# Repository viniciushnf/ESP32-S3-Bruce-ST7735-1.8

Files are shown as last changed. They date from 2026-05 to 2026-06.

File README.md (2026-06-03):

<p align="center">
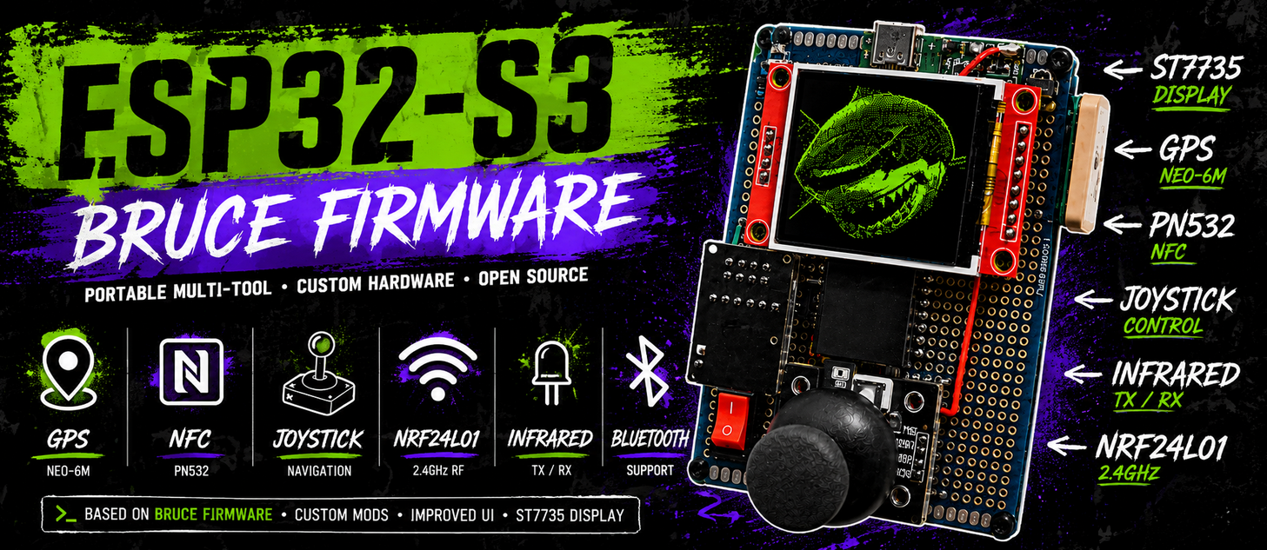
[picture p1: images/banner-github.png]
ESP32-S3 Banner
  
</p>

# ESP32-S3 + Bruce Firmware | 1.8" ST7735 Display, GPS, NFC, NRF24L01, IR & Joystick

This project combines multiple modules into a single portable Bruce Firmware device, including a TFT display, GPS navigation, NFC communication, NRF24L01 RF communication, infrared functionality, joystick control, SD card storage, and battery monitoring.

<p align="center">
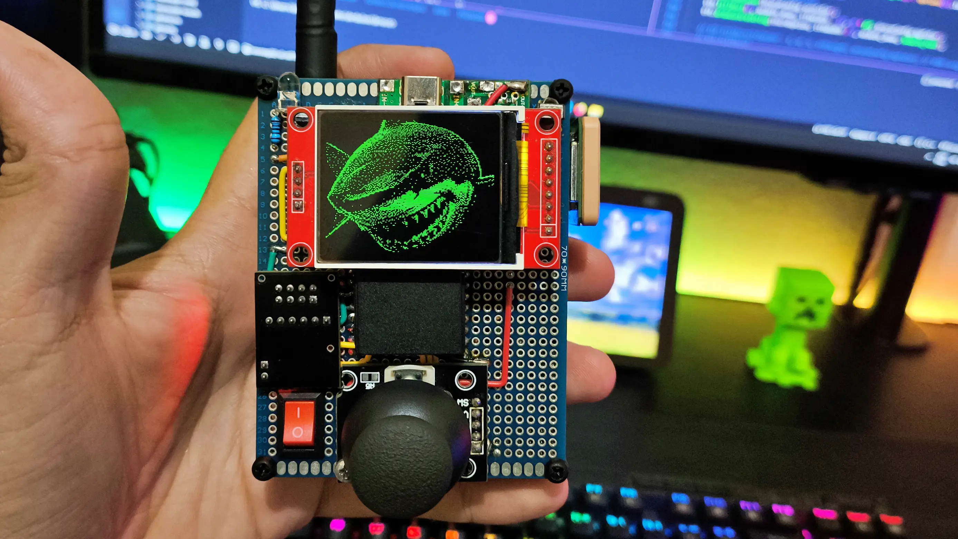
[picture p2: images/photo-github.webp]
ESP32-S3 photo
  
</p>

---

## YouTube Video

<p align="center">
  <a href="https://www.youtube.com/watch?v=Ke6ndQEae68" align="center">
    YouTube Video
  </a>
</p>

**Video:**
https://www.youtube.com/watch?v=Ke6ndQEae68

---

## :zap: Features

### Wi-Fi
- Wi-Fi scanning and network analysis
- Wi-Fi penetration testing tools 
- Packet monitoring and wireless network reconnaissance
- Wi-Fi attacks

### Bluetooth
- Bluetooth device scanning
- Bluetooth Low Energy (BLE) tools
- Bluetooth testing and analysis features

### RF (NRF24L01)
- RF Jammer
- RF Spectrum
- MouseJack

### GPS
- Real-time GPS positioning
- Display latitude, longitude, altitude, speed, and satellite information
- Save GPS data to the SD card

### NFC (PN532)
- Read NFC tags
- Write data to NFC tags
- NFC tag information analysis

### Infrared (IR)
- Receive infrared signals
- Transmit infrared signals
- Store and replay captured IR codes

### SD Card
- Browse files and folders
- Store captured data and logs
- Load and save configuration files

### Power Management
- Battery voltage monitoring
- Rechargeable 18650 battery support
- Integrated charging and voltage regulation

---

## :rocket: Hardware Used

* ESP32-S3
* 1.8" ST7735 TFT Display with SD Card Reader
* NEO-6M GPS Module
* PN532 NFC Module
* NRF24L01 with Adapter
* Infrared Transmitter and Receiver
* Joystick Module
* 18650 Li-ion Battery
* J5019 (TP4056 + MT3608) Battery Charging and 5V Regulation Module

---

## :toolbox: Other Components Used

* Wires
* 2× Perfboards (26 × 31 holes / 70 × 90 mm)
* Nylon Screws and Spacers
* On/Off Switch
* 18650 Battery Holder
* Male and Female Pin Headers
* 1× 100 Ω Resistor
* 1× 220 Ω Resistor
* 1× 1 kΩ Resistor
* 2× 100 kΩ Resistors
* 2× 100 nF Ceramic Capacitors
* 1× 2N2222 Transistor

---

## :clipboard: Wiring Diagram and Documentation

* The module pinout can be found in: wiring-diagram/pinout.txt
* The wiring diagram can be found in: wiring-diagram/wiring-diagram.png
* Hardware assembly photos can be found in: images/
* The installation guide can be found in: installation-guide.txt

---

## :wrench: Bruce Firmware Modifications

* Several Bruce Firmware files were modified to adapt the interface to the 1.8" ST7735 display.
* Additional features and improvements were added to the firmware.
* The installation guide explaining how to upload the modified firmware can be found in: installation-guide.txt

---

## :battery: Battery Life

* During testing, the device achieved more than **8 hours of continuous operation** using a **3000 mAh 18650 Li-ion battery**.
* Actual battery life may vary depending on several factors, including battery capacity and quality, display brightness, active modules, enabled features, wireless activity, and overall device usage.
* As a result, operating time may be shorter or longer than the value observed during testing.

---

## :information_source: Important Notes

* All features were tested under controlled conditions. Performance may vary depending on hardware variations and configuration.
* I recommend testing all components on a breadboard before assembling the final device. Be sure to verify the pinout, operating voltage, and specifications of each module, as different versions may have different requirements.
* Carefully check all power connections and ensure that every module is compatible with your chosen power supply. Testing everything beforehand can help identify wiring issues, compatibility problems, and configuration mistakes before final assembly.

---

## :shark: Bruce Firmware

Official Bruce Firmware project:

* https://bruce.computer/
* https://github.com/BruceDevices/firmware

---

## :warning: Disclaimer

* This project is intended for educational, research, and development purposes only.
* The author assumes no responsibility for any damage to hardware, software, property, legal issues, or data resulting from the use or misuse of the information, files, or materials provided in this repository.
* Users are responsible for ensuring compliance with all applicable laws, regulations, and policies in their jurisdiction. This project should only be used in authorized environments and in a responsible and ethical manner.
* No warranty is provided regarding the accuracy, completeness, reliability, or suitability of the hardware designs, firmware modifications, wiring diagrams, or documentation contained in this repository.
* By using this project, you acknowledge that you do so at your own risk.

---

## :wave: Get in touch

If you build this project, I'd love to see the result! 

If you have any questions, suggestions, or run into any issues, feel free to contact me on Instagram. 

I'm always happy to help, receive feedback, and see what the community creates. 

I'm also open to collaborations and partnership opportunities related to electronics, embedded systems, and open-source projects.

* Instagram: **@viniciushnf**
* https://www.instagram.com/viniciushnf/

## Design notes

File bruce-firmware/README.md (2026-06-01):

Bruce Main Menu

# :shark: Bruce

Bruce is a versatile ESP32 firmware that supports a ton of offensive features focusing on facilitating Red Team operations.
It also supports M5stack and Lilygo products and works great with Cardputer, Sticks, M5Cores, T-Decks and T-Embeds.

**Check our fully open-source hardware too:** https://bruce.computer/boards

## :building_construction: How to install

### The easiest way to install Bruce is using our official Web Flasher!
### Check out: https://bruce.computer/flasher

Alternatively, you can download the latest binary from releases or actions and flash locally using esptool.py
```sh
esptool.py --port /dev/ttyACM0 write_flash 0x00000 Bruce-<device>.bin
```

**For m5stack devices**

If you already use M5Launcher to manage your m5stack device, you can install it with OTA

Or you can burn it directly from the [m5burner tool](https://docs.m5stack.com/en/download), just search for 'Bruce' (My official builds will be uploaded by "owner" and have photos.) on the device category you want to and click on burn

## :keyboard: Discord Server

Contact us in our [Discord Server](https://discord.gg/WJ9XF9czVT)!

## :bookmark_tabs: Wiki

For more information on each function supported by Bruce, [read our wiki here](https://github.com/pr3y/Bruce/wiki).
Also, [read our FAQ](https://github.com/pr3y/Bruce/wiki/FAQ)

## :computer: List of Features

<details>
  <summary><h2>WiFi</h2></summary>

- [x] Connect to WiFi
- [x] WiFi AP
- [x] Disconnect WiFi
- [x] [WiFi Atks](https://github.com/pr3y/Bruce/wiki/WiFi#wifi-atks)
  - [x] [Beacon Spam](https://github.com/pr3y/Bruce/wiki/WiFi#beacon-spam)
  - [x] [Target Atk](https://github.com/pr3y/Bruce/wiki/WiFi#target-atk)
    - [x] Information
    - [x] Target Deauth
    - [x] EvilPortal + Deauth
  - [x] Deauth Flood (More than one target)
- [x] [Wardriving](https://github.com/pr3y/Bruce/wiki/Wardriving)
- [x] [TelNet](https://github.com/pr3y/Bruce/wiki/WiFi#telnet)
- [x] [SSH](https://github.com/pr3y/Bruce/wiki/WiFi#ssh)
- [x] [RAW Sniffer](https://github.com/pr3y/Bruce/wiki/WiFi#raw-sniffer)
- [x] [TCP Client](https://github.com/pr3y/Bruce/wiki/WiFi#tcp-client)
- [x] [TCP Listener](https://github.com/pr3y/Bruce/wiki/WiFi#tcp-listener)
- [x] [Evil Portal](https://github.com/pr3y/Bruce/wiki/WiFi#evil-portal)
- [x] [Scan Hosts](https://github.com/pr3y/Bruce/wiki/WiFi#evil-portal) (with TCP Port scanning)
- [x] [Responder](https://github.com/BruceDevices/firmware/wiki/WiFi#responder)
- [x] [Arp Spoofing](https://github.com/BruceDevices/firmware/wiki/WiFi#arp-spoofing)
- [x] [Arp Poisoning](https://github.com/BruceDevices/firmware/wiki/WiFi#arp-poisoning)
- [x] [Wireguard Tunneling](https://github.com/pr3y/Bruce/wiki/WiFi#wireguard-tunneling)
- [x] Brucegotchi
  - [x] Pwnagotchi friend
  - [x] Pwngrid spam faces & names
    - [x] [Optional] DoScreen a very long name and face
    - [x] [Optional] Flood uniq peer identifiers

</details>

<details>
  <summary><h2>BLE</h2></summary>

- [X] [BLE Scan](https://github.com/pr3y/Bruce/wiki/BLE#ble-scan)
- [X] Bad BLE - Run Ducky scripts, similar to [BadUsb](https://github.com/pr3y/Bruce/wiki/Others#badusb)
- [X] BLE Keyboard - Cardputer and T-Deck Only
- [X] iOS Spam
- [X] Windows Spam
- [X] Samsung Spam
- [X] Android Spam
- [X] Spam All
</details>

<details>
  <summary><h2>RF</h2></summary>

- [x] Scan/Copy
- [x] [Custom SubGhz](https://github.com/pr3y/Bruce/wiki/RF#replay-payloads-like-flipper)
- [x] Spectrum
- [x] Jammer Full (sends a full squared wave into output)
- [x] Jammer Intermittent (sends PWM signal into output)
- [x] Config
    - [X] RF TX Pin
    - [X] RF RX Pin
    - [X] RF Module
        - [x] RF433 T/R M5Stack
        - [x] [CC1101 (Sub-Ghz)](https://github.com/pr3y/Bruce/wiki/CC1101)
    - [X] RF Frequency
- [x] Replay
</details>

<details>
  <summary><h2>RFID</h2></summary>

- [x] Read tag
- [x] Read 125kHz
- [x] Clone tag
- [x] Write NDEF records
- [x] Amiibolink
- [x] Chameleon
- [x] Write data
- [x] Erase data
- [x] Save file
- [x] Load file
- [x] Config
    - [X] [RFID Module](https://github.com/pr3y/Bruce/wiki/RFID#supported-modules)
        - [x] PN532
        - [x] PN532Killer
- [ ] Emulate tag
</details>

<details>
  <summary><h2>IR</h2></summary>

- [x] TV-B-Gone
- [x] IR Receiver
- [x] [Custom IR (NEC, NECext, SIRC, SIRC15, SIRC20, Samsung32, RC5, RC5X, RC6)](https://github.com/pr3y/Bruce/wiki/IR#replay-payloads-like-flipper)
- [x] Config
    - [X] Ir TX Pin
    - [X] Ir RX Pin
</details>

<details>
  <summary><h2>FM</h2></summary>

- [x] [Broadcast standard](https://github.com/pr3y/Bruce/wiki/FM#play_or_pause_button-broadcast-standard)
- [x] [Broadcast reserved](https://github.com/pr3y/Bruce/wiki/FM#no_entry_sign-broadcast-rerserved)
- [x] [Broadcast stop](https://github.com/pr3y/Bruce/wiki/FM#stop_button-broadcast-stop)
- [ ] [FM Spectrum](https://github.com/pr3y/Bruce/wiki/FM#ocean-fm-spectrum)
- [ ] [Hijack Traffic Announcements](https://github.com/pr3y/Bruce/wiki/FM#car-hijack-ta)
- [ ] [Config](https://github.com/pr3y/Bruce/wiki/FM#bookmark_tabs-config)
</details>

<details>
  <summary><h2>NRF24</h2></summary>

- [X] [NRF24 Jammer](https://github.com/pr3y/Bruce/wiki/BLE#nrf24-jammer)
- [X] 2.4G Spectrum
- [ ] Mousejack
</details>

<details>
  <summary><h2>Scripts</h2></summary>

- [X] [JavaScript Interpreter](https://github.com/pr3y/Bruce/wiki/Interpreter) [Credits to justinknight93](https://github.com/justinknight93/Doolittle)
</details>

<details>
  <summary><h2>Others</h2></summary>

- [X] Mic Spectrum
- [X] QRCodes
    - [x] Custom
    - [x] PIX (Brazil bank transfer system)
- [x] [SD Card Mngr](https://github.com/pr3y/Bruce/wiki/Others#sd-card-mngr)
    - [x] View image (jpg)
    - [x] File Info
    - [x] [Wigle Upload](https://github.com/pr3y/Bruce/wiki/Wardriving#how-to-upload)
    - [x] Play Audio
    - [x] View File
- [x] [LittleFS Mngr](https://github.com/pr3y/Bruce/wiki/Others#littlefs-mngr)
- [x] [WebUI](https://github.com/pr3y/Bruce/wiki/Others#webui)
    - [x] Server Structure
    - [x] Html
    - [x] SDCard Mngr
    - [x] Spiffs Mngr
- [x] Megalodon
- [x] [BADUsb (New features, LittleFS and SDCard)](https://github.com/pr3y/Bruce/wiki/Others#badusb)
- [x] USB Keyboard - Cardputer and T-Deck Only
- [x] [iButton](https://github.com/pr3y/Bruce/wiki/Others#ibutton)
- [x] [LED Control](https://github.com/pr3y/Bruce/wiki/Others#led-control)
</details>

<details>
  <summary><h2>Clock</h2></summary>

- [X] RTC Support
- [X] NTP time adjust
- [X] Manual adjust
</details>

<details>
  <summary><h2>Connect (ESPNOW)</h2></summary>

- [X] Send File
- [X] Receive File
- [X] Send Commands
- [X] Receive Commands
</details>

<details>
  <summary><h2>Config</h2></summary>

- [x] Brightness
- [x] Dim Time
- [x] Orientation
- [X] UI Color
- [x] Boot Sound on/off
- [x] Clock
- [x] Sleep
- [x] Restart
</details>

## Specific functions per Device, the ones not mentioned here are available to all.
| Device | CC1101 | NRF24 | FM Radio  | PN532 | Mic | BadUSB | RGB Led | Speaker | Fuel Guage | LITE_VERSION |
| --- | :---: | :---: | :---: | :---: | :---: | :---: | :---: | :---: | :---: | :---: |
| [M5Stack Cardputer](https://shop.m5stack.com/products/m5stack-cardputer-kit-w-m5stamps) (and ADV) | :ok: | :ok: | :ok: | :ok: | :ok:  | :ok: | :ok: | NS4168 | :x: | :x: |
| [M5Stack M5StickC PLUS2](https://shop.m5stack.com/products/m5stickc-plus2-esp32-mini-iot-development-kit)  | :ok: | :ok: | :ok: | :ok: | :ok:  | :ok:¹ | :x: | Tone | :x: | :x: |
| [M5Stack M5StickC PLUS](https://shop.m5stack.com/products/m5stickc-plus-esp32-pico-mini-iot-development-kit) | :ok: | :ok: | :ok: | :ok: | :ok:  | :ok:¹ | :x: | Tone | :x: | :x:² |
| [M5Stack M5Core BASIC](https://shop.m5stack.com/products/basic-core-iot-development-kit) | :ok: | :ok: | :ok: | :ok: | :ok:  | :ok:¹ | :x: | Tone | :x: | :x: |
| [M5Stack M5Core2](https://shop.m5stack.com/products/m5stack-core2-esp32-iot-development-kit-v1-1) | :ok: | :ok: | :ok: | :ok: | :ok:  | :ok:¹ | :x: | :x: | :x: | :x: |
| [M5Stack M5CoreS3](https://shop.m5stack.com/products/m5stack-cores3-esp32s3-lotdevelopment-kit)/[SE](https://shop.m5stack.com/products/m5stack-cores3-se-iot-controller-w-o-battery-bottom) | :ok: | :ok: | :ok: | :ok: | :x: | :ok: | :x: | :x: | :x: | :x: |
| [JCZN CYD&#x2011;2432S028](https://www.aliexpress.us/item/3256804774970998.html) | :ok: | :ok: | :ok: | :ok: | :x: | :ok:¹ | :x: | :x: | :x: | :x:² |
| [Lilygo T&#x2011;Embed CC1101](https://lilygo.cc/products/t-embed-cc1101) | :ok: | :ok: | :ok: | :ok: | :ok:  | :ok: | :ok: | :ok: | :ok: | :x: |
| [Lilygo T&#x2011;Embed](https://lilygo.cc/products/t-embed) | :ok: | :ok: | :ok: | :ok: | :ok:  | :ok: | :ok: | :ok: | :x: | :x: |
| [Lilygo T-Display-S3](https://lilygo.cc/products/t-display-s3) | :ok: | :ok: | :x: | :x: | :x: | :ok: | :x: | :x: | :x: | :x: |
| [Lilygo T&#x2011;Deck](https://lilygo.cc/products/t-deck) ([and pro](https://lilygo.cc/products/t-deck-plus-1)) | :ok: | :x: | :x: | :x: | :x: | :ok: | :x: | :x: | :x: | :x: |
| [Lilygo T-Watch-S3](https://lilygo.cc/products/t-watch-s3) | :x: | :x: | :x: | :x: | :x: | :ok: | :x: | :x: | :x: | :x: |
| [Lilygo T-LoRa Pager](https://lilygo.cc/products/t-lora-pager) | :x: | :x: | :x: | :x: | :x: | :ok: | :x: | :x: | :x: | :x: |
| [Smoochiee V2](https://www.pcbway.com/project/shareproject/Bruce_PCB_Smoochiee_d6a0284b.html) | :ok: | :ok: | :x: | :ok: | :x: | :ok: | :x: | :x: | :x: | :x: |
| [ESP32-C5](https://docs.espressif.com/projects/esp-dev-kits/en/latest/esp32c5/esp32-c5-devkitc-1/user_guide.html) | :ok: | :ok: | :x: | :ok: | :x: | :x: | :x: | :x: | :x: | :x: |
| [Bruce RF Reaper](https://www.elecrow.com/bruce-pcb-rf-reaper.html) | :ok: | :ok: | :x: | :x: but w/ ST25R3916 | :x: | :ok: | :ok: | :x: | :ok: | :x: |

² CYD have a LITE_VERSION version for Launcher Compatibility
¹ Core, CYD and StickCs Bad-USB: [here](https://github.com/pr3y/Bruce/wiki/Others#badusb)

*LITE_VERSION*: TelNet, SSH, WireGuard, ScanHosts, RawSniffer, Brucegotchi, BLEBacon, BLEScan and Interpreter are NOT available for M5Launcher Compatibility

## :sparkles: Why and how does it look?

Bruce stems from a keen observation within the community focused on devices like Flipper Zero. While these devices offered a glimpse into the world of offensive security, there was a palpable sense that something more could be achieved without being that overpriced, particularly with the robust and modular hardware ecosystem provided by ESP32 Devices, Lilygo and M5Stack products.

Bruce Main Menu
Bruce on M5Core
Bruce on Stick
Bruce on CYD

Other media can be [found here](./media/).

## :clap: Acknowledgements

+ [@bmorcelli](https://github.com/bmorcelli) for new core and a bunch of new features, also porting to many devices!
+ [@IncursioHack](https://github.com/IncursioHack) for adding RF and RFID modules features.
+ [@Luidiblu](https://github.com/Luidiblu) for logo and UI design assistance.
+ [@eadmaster](https://github.com/eadmaster) for adding a lot of features.
+ [@rennancockles](https://github.com/rennancockles) for a lot of RFID code, refactoring and others features.
+ [@7h30th3r0n3](https://github.com/7h30th3r0n3) refactoring and a lot of help with WiFi attacks.
+ [@Tawank](https://github.com/Tawank) refactoring interpreter among many other things
+ [@pablonymous]() new RF functions to read RAW Data
+ [Smoochiee]() for Bruce PCB design.
+ [TH3_KR4K3N]() for Stick cplus extender PCB design.
+ Everyone who contributed in some way to the project, thanks :heart:

## :construction: Disclaimer

Bruce is a tool for cyber offensive and red team operations, distributed under the terms of the Affero General Public License (AGPL). It is intended for legal and authorized security testing purposes only. Use of this software for any malicious or unauthorized activities is strictly prohibited. By downloading, installing, or using Bruce, you agree to comply with all applicable laws and regulations. This software is provided free of charge, and we do not accept payments for copies or modifications. The developers of Bruce assume no liability for any misuse of the software. Use at your own risk.

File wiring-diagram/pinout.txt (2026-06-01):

Module pin ---> ESP32-S3 GPIO

---- DISPLAY ----
LED BL -----> 4
SCK (SCLK) -> 5
SDA (MOSI) -> 6
AO (DC) ----> 7
RESET ------> 15
CS ---------> 16

---- SD CARD ----
CS ---> 40
MOSI -> 6
MISO -> 41
SCK --> 5

--- NRF24L01 -----
CE -----> 21
CSN/SS -> 47
SCK ----> 5
MOSI ---> 6
MISO ---> 41
IRQ ----> 35

---- JOYSTICK ----
VR-X -> 12
VR-Y -> 13
SW ---> 14

------ I2C ------
SDA -> 18
SCL -> 8

------- IR -------
TX -> 1
RX -> 2

------ GPS ------
GPS TX -> 38 (RX)
GPS RX -> 17 (TX)

---- BATTERY ----
BAT -> 10

- - - - - - - - -

Attention:

I recommend testing all components on a breadboard before assembling the final device. Be sure to verify the pinout,
operating voltage, and specifications of each module, as different versions may have different requirements.

Carefully check the power connections and ensure that all modules are compatible with your chosen power supply.
Testing everything beforehand can help identify wiring issues, compatibility problems, and configuration mistakes before the final assembly.

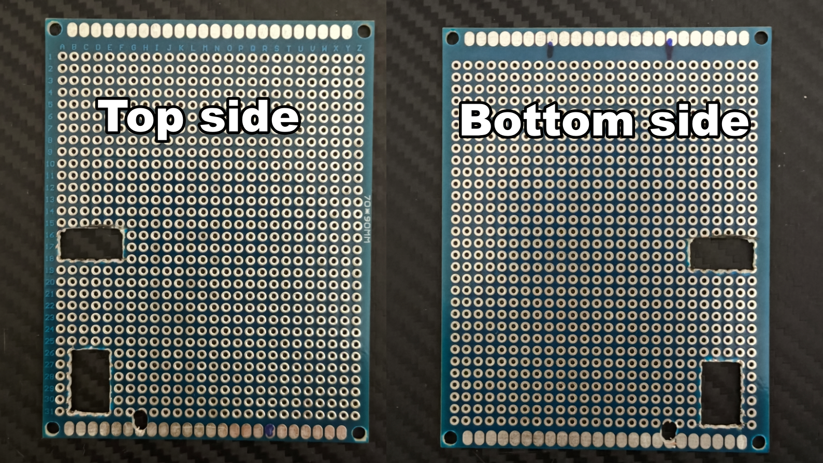
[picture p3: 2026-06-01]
images/holes-in-the-PCB-1.png

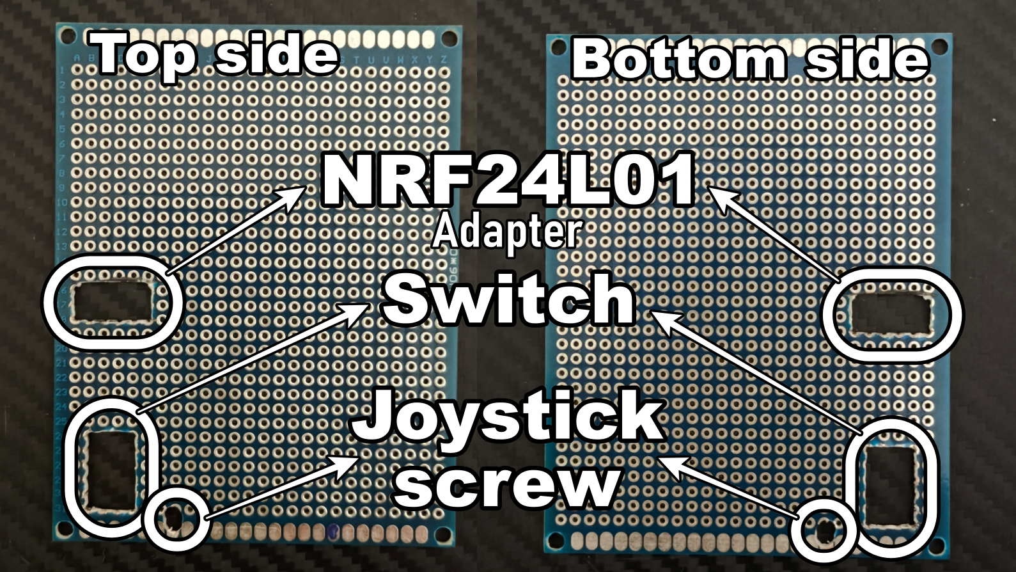
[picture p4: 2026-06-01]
images/holes-in-the-PCB-2.png

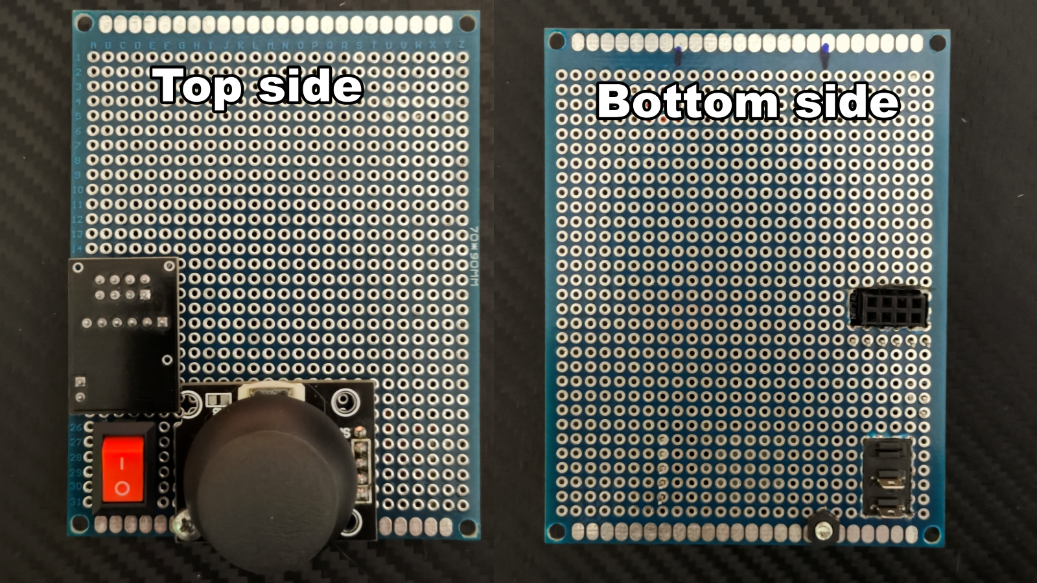
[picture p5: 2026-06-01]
images/holes-in-the-PCB-3.png

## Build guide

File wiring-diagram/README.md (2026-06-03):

# PINOUT

## :electric_plug: Module pin ---> ESP32-S3 GPIO

### Display

| Display Pin | ESP32-S3 |
|---|---|
| LED BL | GPIO 4 |
| SCK (SCLK) | GPIO 5 |
| SDA (MOSI) | GPIO 6 |
| A0 (DC) | GPIO 7 |
| RESET | GPIO 15 |
| CS | GPIO 16 |

### SD Card

| SD Card Pin | ESP32-S3 |
|---|---|
| CS | GPIO 40 |
| MOSI | GPIO 6 |
| MISO | GPIO 41 |
| SCK | GPIO 5 |

### NRF24L01

| NRF24L01 Pin | ESP32-S3 |
|---|---|
| CE | GPIO 21 |
| CSN / SS | GPIO 47 |
| SCK | GPIO 5 |
| MOSI | GPIO 6 |
| MISO | GPIO 41 |
| IRQ | GPIO 35 |

### Joystick

| Joystick Pin | ESP32-S3 |
|---|---|
| VR-X | GPIO 12 |
| VR-Y | GPIO 13 |
| SW | GPIO 14 |

### I2C

| I2C Pin | ESP32-S3 |
|---|---|
| SDA | GPIO 18 |
| SCL | GPIO 8 |

### Infrared

| IR Pin | ESP32-S3 |
|---|---|
| TX | GPIO 1 |
| RX | GPIO 2 |

### GPS

| GPS Pin | ESP32-S3 |
|---|---|
| GPS TX → ESP32 RX | GPIO 38 |
| GPS RX → ESP32 TX | GPIO 17 |

### Battery Monitoring

| Signal | ESP32-S3 |
|---|---|
| BAT | GPIO 10 |

---

<p align="center">
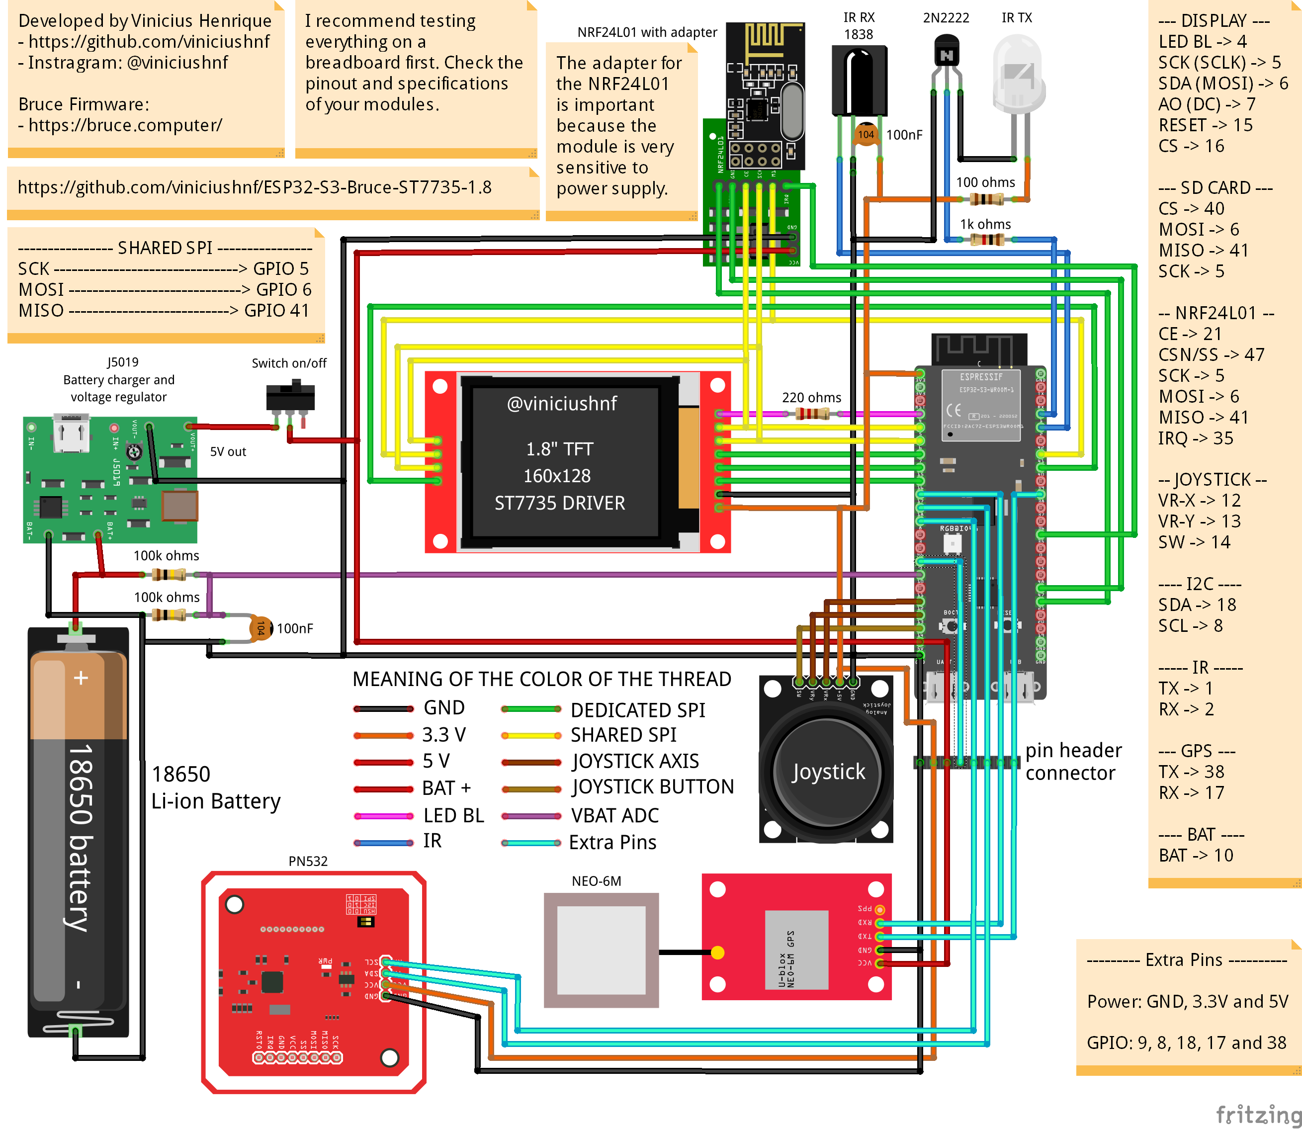
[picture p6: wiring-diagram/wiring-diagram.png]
ESP32-S3 pinout
  
</p>

---

## :warning: Attention:

* I recommend testing all components on a breadboard before assembling the final device. Be sure to verify the pinout,
operating voltage, and specifications of each module, as different versions may have different requirements.

* Carefully check the power connections and ensure that all modules are compatible with your chosen power supply.

* Testing everything beforehand can help identify wiring issues, compatibility problems, and configuration mistakes before the final assembly.

---

## :battery: Battery Charger and Monitoring Circuit

* This project uses a J5019 module, which combines a TP4056 Li-ion battery charger and an MT3608 boost converter. The TP4056 safely charges the 18650 battery, while the MT3608 boosts the battery voltage to a stable 5V output for the ESP32-S3.

* Battery voltage is monitored using a voltage divider made of two 100 kΩ resistors, reducing the battery voltage by half before it reaches the ESP32-S3 ADC pin. This is necessary because a Li-ion battery can reach 4.2V, which is too high for direct ADC measurement.

* A 100 nF capacitor helps filter noise and improves battery voltage readings. Always verify your module specifications and test the circuit before final assembly.

---

## :information_source: NRF24L01 adapter

* The NRF24L01 is sensitive to power supply fluctuations and can become unstable when powered directly from the ESP32-S3. 

* The NRF24L01 adapter includes a voltage regulator and filtering capacitors that provide a stable 3.3V supply, improving reliability, communication range, and overall performance. 

* Using the adapter is highly recommended to prevent connection issues, random resets, and packet loss.

---

## :bulb: Infrared Transmitter Circuit

* The 2N2222 transistor is used to drive the infrared transmitting LED. 

* An ESP32-S3 GPIO cannot safely provide the current required for a powerful IR transmission, so the transistor acts as a switch that allows the LED to draw more current directly from the power supply. 

* This increases the infrared signal strength, improves transmission range, and helps protect the ESP32-S3 GPIO from excessive current.

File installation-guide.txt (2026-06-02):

ESP32-S3 Bruce Firmware Installation Guide

This guide explains how to install and upload the modified Bruce Firmware included in this repository to an ESP32-S3 board.

Repository:
https://github.com/viniciushnf/ESP32-S3-Bruce-ST7735-1.8

------------------------------------------------

OPTION 1 - BUILD AND UPLOAD THE SOURCE CODE
(RECOMMENDED FOR CUSTOMIZATION AND DEVELOPMENT)

Requirements:

* ESP32-S3 board
* USB data cable
* Visual Studio Code
* PlatformIO extension for VS Code
* Python 3.x

Step 1 - Download the Repository

* Download or clone this repository: https://github.com/viniciushnf/ESP32-S3-Bruce-ST7735-1.8

* The modified Bruce Firmware source code is located in: bruce-firmware/

Step 2 - Install Python

Download and install Python: https://www.python.org/downloads/

Important:

During installation, enable the option: "Add Python to PATH"

Verify the installation:

Open a terminal and run:
python --version
or
python3 --version

Step 3 - Install Visual Studio Code

Download and install Visual Studio Code: https://code.visualstudio.com/

Step 4 - Install PlatformIO

1. Open Visual Studio Code.
2. Open the Extensions tab.
3. Search for:

PlatformIO IDE

4. Install the extension.
5. Restart Visual Studio Code if required.

Step 5 - Open the Firmware Project

1. Open Visual Studio Code.

2. Select: File -> Open Folder

3. Open the folder: bruce-firmware

4. Wait for PlatformIO to initialize the project.

The first initialization may take several minutes because PlatformIO will automatically download the required toolchains and libraries.

Step 6 - Connect the ESP32-S3

Connect the ESP32-S3 board to the computer using a USB data cable.

Wait for the operating system to recognize the device.

Step 7 - Verify the Selected Environment

Open the file: platformio.ini

Verify that the correct ESP32-S3 environment is selected for your hardware.

The repository already contains the configuration used for this project.

Step 8 - Compile the Firmware

Click the Build button in PlatformIO or run: pio run

The compilation process may take several minutes during the first build.

Step 9 - Upload the Firmware

Click the Upload button in PlatformIO or run: pio run --target upload

Wait until the upload process finishes successfully.

Step 10 - Monitor the Serial Port (Optional)

To open the serial monitor:
pio device monitor
or use the PlatformIO Serial Monitor button.

------------------------------------------------

OPTION 2 - FLASH THE PRECOMPILED BIN FILE
(FASTEST METHOD)

This is the easiest way to install Bruce Firmware on the ESP32-S3 without compiling the source code.

The precompiled firmware file is located in: bruce-firmware/Bruce-esp32-s3-st7735.bin

Requirements:
* ESP32-S3 board
* USB cable
* Google Chrome browser (recommended)
* Internet connection

I strongly recommend using Google Chrome to access the ESPTool Web Flasher. Other browsers may also work, but Chrome currently provides the best compatibility and Web Serial support.

ESPTool Web Flasher: https://espressif.github.io/esptool-js/

Tested Hardware:
This procedure was tested on an ESP32-S3-WROOM-1-N16R8 and worked perfectly.

The N16R8 version has:
* 16 MB Flash
* 8 MB PSRAM

Installation Steps:

1. Connect the ESP32-S3 to your computer using a USB cable.

2. Open Google Chrome.

3. Open the ESPTool Web Flasher: https://espressif.github.io/esptool-js/

4. Click "Connect".

5. Select the correct COM port for your ESP32-S3.

6. Click "Erase Flash".
(This step is highly recommended because it removes old firmware, partition tables, and flash configurations that could prevent the firmware from booting correctly.)

7. After the erase process finishes, select the firmware file: Bruce-esp32-s3-st7735.bin
* located in: bruce-firmware/Bruce-esp32-s3-st7735.bin

8. Configure the flashing parameters exactly as follows:
* Address: 0x0
* Flash Mode: DIO
* Flash Frequency: 40M
* Flash Size: 16 MB

9. Click "Program".

10. Wait for the flashing process to complete.

11. After the upload finishes, the ESP32-S3 may not automatically reboot. If that happens, simply disconnect and reconnect power, or press the RESET button.

12. The Bruce Firmware should now start normally.

Notes for ESP32-S3 N16R8 Users

If your board is an ESP32-S3-WROOM-1-N16R8, use:
* Address: 0x0
* Flash Mode: DIO
* Flash Frequency: 40M
* Flash Size: 16 MB

These settings were tested and verified to work correctly.

What If My ESP32-S3 Is Not an N16R8?

The most important parameter is the Flash Size.

Different ESP32-S3 modules may have different flash capacities:

N4  = 4 MB Flash
N8  = 8 MB Flash
N16 = 16 MB Flash
N32 = 32 MB Flash

If your board is not an N16R8, select the Flash Size that matches your hardware.

Examples:

ESP32-S3 N8:
Flash Size = 8 MB

ESP32-S3 N16:
Flash Size = 16 MB

ESP32-S3 N32:
Flash Size = 32 MB

You can usually find the flash size:

* Printed on the module
* In the product specifications
* In the board documentation

If you are unsure about your board specifications, check the manufacturer's documentation before flashing.

Troubleshooting

Firmware uploads successfully but does not boot:
* Perform "Erase Flash" again.
* Reflash the firmware.
* Verify that Flash Size matches your hardware.
* Verify that Address is set to 0x0.
* Verify that Flash Mode is set to DIO.
* Verify that Flash Frequency is set to 40M.

ESP32-S3 does not reboot automatically:
* Press the RESET button.
* Or disconnect and reconnect power.

The firmware was successfully tested using:
* ESP32-S3-WROOM-1-N16R8
* Flash Size: 16 MB
* Flash Mode: DIO
* Flash Frequency: 40M
* Address: 0x0
* ESPTool Web Flasher (Chrome)
------------------------------------------------

### IMPORTANT NOTES ###

* Verify all wiring before powering the device.
* Make sure the display, GPS, NFC, NRF24L01, infrared modules, joystick, and other peripherals are connected according to the wiring diagram provided in this repository.
* Different module versions may use different pinouts or operating voltages.
* Always check the specifications of your hardware before connecting power.
* If the board is not detected, verify the USB cable and install the appropriate USB-to-Serial drivers if required.
* Some ESP32-S3 boards may require entering bootloader mode manually during flashing.

Additional Documentation:

* Wiring diagram: wiring-diagram/
* Pinout information: wiring-diagram/pinout.txt
* Hardware photos: images/

For additional information about Bruce Firmware, visit:

https://bruce.computer/
https://github.com/BruceDevices/firmware

------------------------------------------------

Disclaimer:

* This project is intended for educational, research, and development purposes only.
* The author assumes no responsibility for any damage to hardware, software, property, legal issues, or data resulting from the use or misuse of the information, files, or materials provided in this repository.
* Users are responsible for ensuring compliance with all applicable laws, regulations, and policies in their jurisdiction. This project should only be used in authorized environments and in a responsible and ethical manner.
* No warranty is provided regarding the accuracy, completeness, reliability, or suitability of the hardware designs, firmware modifications, wiring diagrams, or documentation contained in this repository.
* By using this project, you acknowledge that you do so at your own risk.

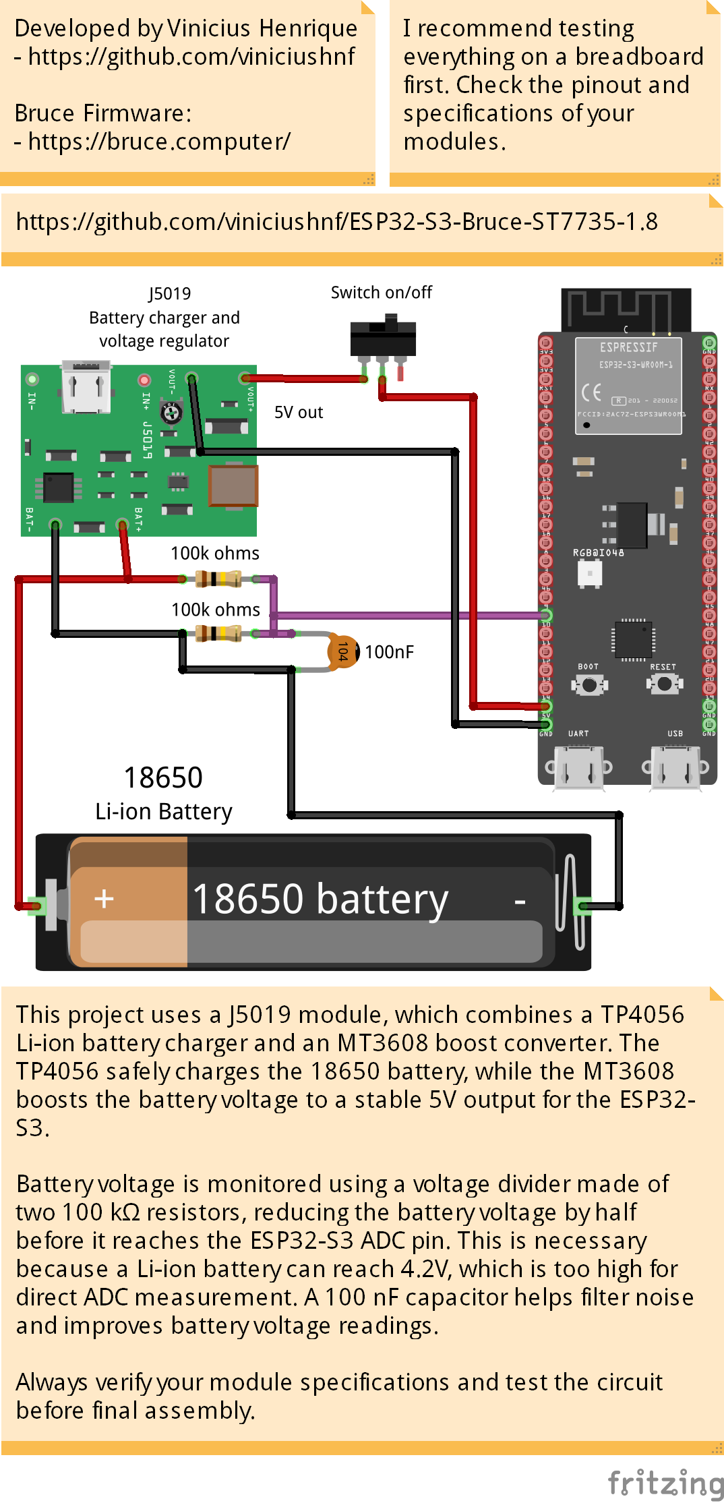
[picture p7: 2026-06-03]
wiring-diagram/power-circuit.png

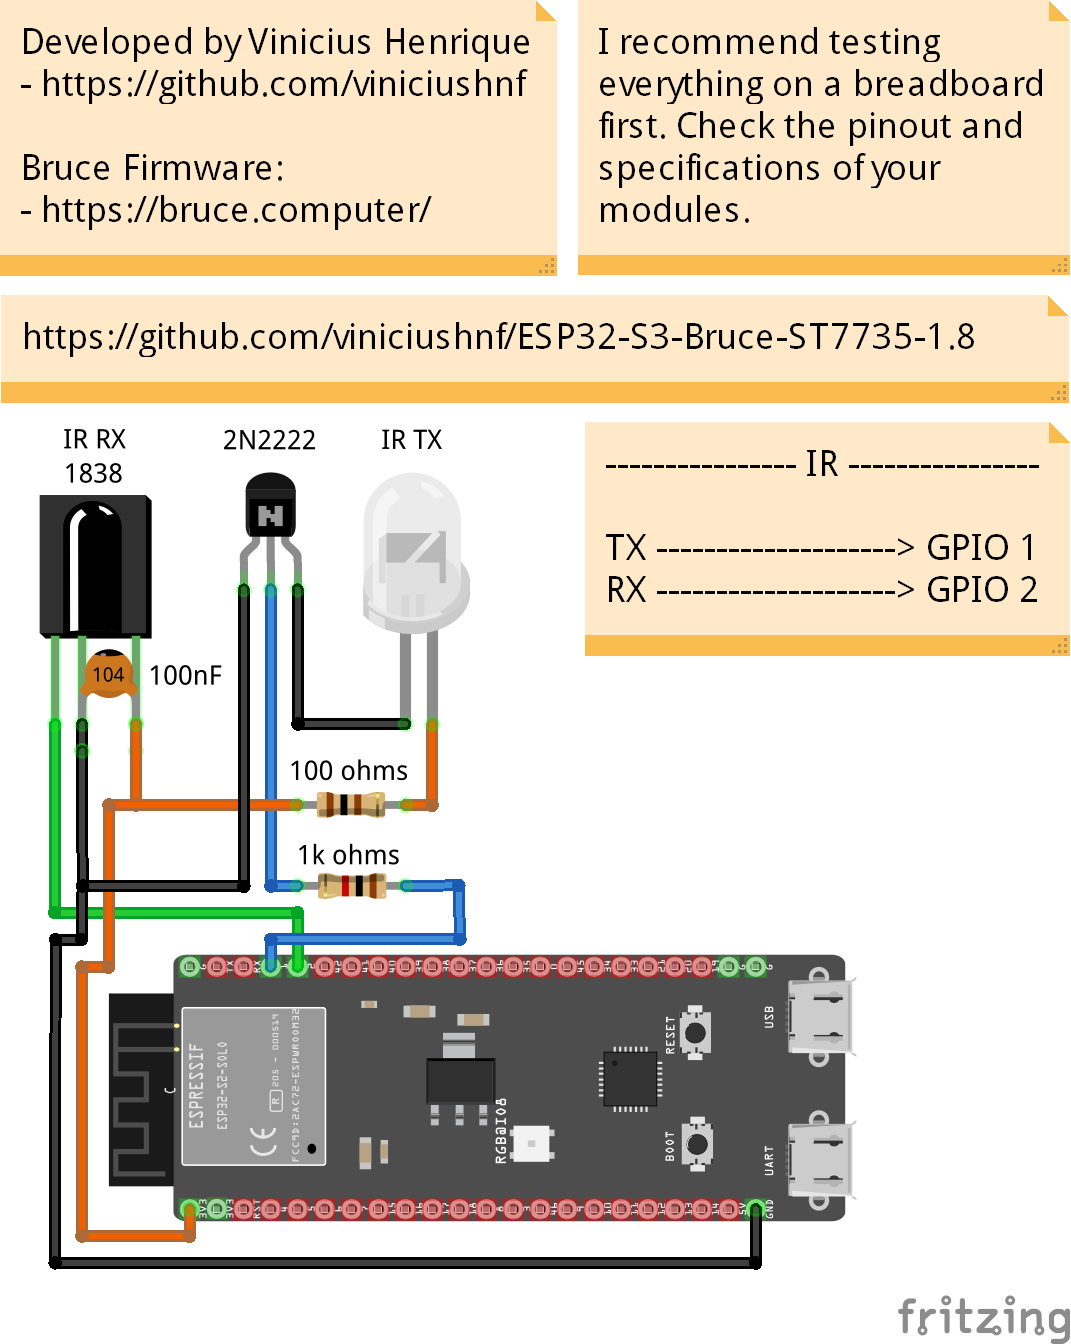
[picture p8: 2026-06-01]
wiring-diagram/ir.png

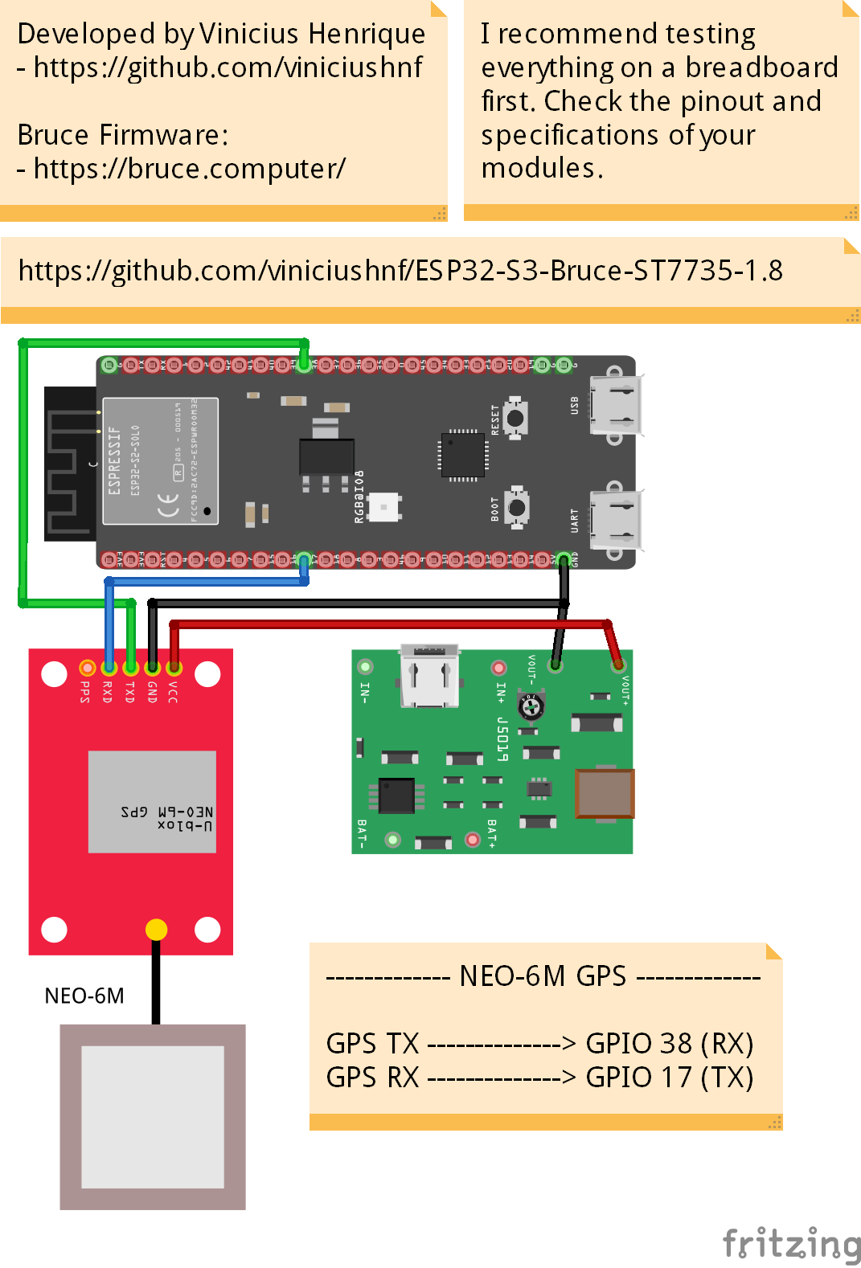
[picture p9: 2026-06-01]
wiring-diagram/neo-6m.png

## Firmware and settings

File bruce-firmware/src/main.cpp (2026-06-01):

#include "core/main_menu.h"
#include <globals.h>

#include "core/powerSave.h"
#include "core/serial_commands/cli.h"
#include "core/utils.h"
#include "current_year.h"
#include "esp32-hal-psram.h"
#include "esp_task_wdt.h"
#include "esp_wifi.h"
#include <functional>
#include <string>
#include <vector>
io_expander ioExpander;
BruceConfig bruceConfig;
BruceConfigPins bruceConfigPins;

SerialCli serialCli;
USBSerial USBserial;
SerialDevice *serialDevice = &USBserial;

StartupApp startupApp;
String startupAppJSInterpreterFile = "";

MainMenu mainMenu;
SPIClass sdcardSPI;
#ifdef USE_HSPI_PORT
#ifndef VSPI
#define VSPI FSPI
#endif
SPIClass CC_NRF_SPI(VSPI);
#else
SPIClass CC_NRF_SPI(HSPI);
#endif

// Navigation Variables
volatile bool NextPress = false;
volatile bool PrevPress = false;
volatile bool UpPress = false;
volatile bool DownPress = false;
volatile bool SelPress = false;
volatile bool EscPress = false;
volatile bool AnyKeyPress = false;
volatile bool NextPagePress = false;
volatile bool PrevPagePress = false;
volatile bool LongPress = false;
volatile bool SerialCmdPress = false;
volatile int forceMenuOption = -1;
volatile uint8_t menuOptionType = 0;
volatile bool OpenQuickAccess = false;
String menuOptionLabel = "";
#ifdef HAS_ENCODER_LED
volatile int EncoderLedChange = 0;
#endif

TouchPoint touchPoint;

keyStroke KeyStroke;

TaskHandle_t xHandle;
void __attribute__((weak)) taskInputHandler(void *parameter) {
    auto timer = millis();
    while (true) {
        checkPowerSaveTime();
        // Sometimes this task run 2 or more times before looptask,
        // and navigation gets stuck, the idea here is run the input detection
        // if AnyKeyPress is false, or rerun if it was not renewed within 75ms (arbitrary)
        // because AnyKeyPress will be true if didn´t passed through a check(bool var)
        if (!AnyKeyPress || millis() - timer > 75) {
            NextPress = false;
            PrevPress = false;
            UpPress = false;
            DownPress = false;
            SelPress = false;
            EscPress = false;
            AnyKeyPress = false;
            SerialCmdPress = false;
            NextPagePress = false;
            PrevPagePress = false;
            touchPoint.pressed = false;
            touchPoint.Clear();
#ifndef USE_TFT_eSPI_TOUCH
            InputHandler();
#endif
            timer = millis();
        }
        vTaskDelay(pdMS_TO_TICKS(10));
    }
}
// Public Globals Variables
unsigned long previousMillis = millis();
int prog_handler; // 0 - Flash, 1 - LittleFS, 3 - Download
String cachedPassword = "";
int8_t interpreter_state = -1;
bool sdcardMounted = false;
bool gpsConnected = false;

// wifi globals
// TODO put in a namespace
bool wifiConnected = false;
bool isWebUIActive = false;
String wifiIP;

bool BLEConnected = false;
bool returnToMenu;
bool isSleeping = false;
bool isScreenOff = false;
bool dimmer = false;
char timeStr[16];
time_t localTime;
struct tm *timeInfo;
#if defined(HAS_RTC)
#if defined(HAS_RTC_PCF85063A)
pcf85063_RTC _rtc;
#else
cplus_RTC _rtc;
#endif
RTC_TimeTypeDef _time;
RTC_DateTypeDef _date;
bool clock_set = true;
#else
ESP32Time rtc;
bool clock_set = false;
#endif

std::vector<Option> options;
// Protected global variables
#if defined(HAS_SCREEN)
tft_logger tft = tft_logger(); // Invoke custom library
tft_sprite sprite = tft_sprite(&tft);
tft_sprite draw = tft_sprite(&tft);
volatile int tftWidth = TFT_HEIGHT;
#ifdef HAS_TOUCH
volatile int tftHeight =
    TFT_WIDTH - 20; // 20px to draw the TouchFooter(), were the btns are being read in touch devices.
#else
volatile int tftHeight = TFT_WIDTH;
#endif
#else
tft_logger tft;
SerialDisplayClass &sprite = tft;
SerialDisplayClass &draw = tft;
volatile int tftWidth = VECTOR_DISPLAY_DEFAULT_HEIGHT;
volatile int tftHeight = VECTOR_DISPLAY_DEFAULT_WIDTH;
#endif

#include "core/display.h"
#include "core/led_control.h"
#include "core/mykeyboard.h"
#include "core/sd_functions.h"
#include "core/serialcmds.h"
#include "core/settings.h"
#include "core/wifi/webInterface.h"
#include "core/wifi/wifi_common.h"
#include "modules/bjs_interpreter/interpreter.h" // for JavaScript interpreter
#include "modules/others/audio.h"                // for playAudioFile
#include "modules/rf/rf_utils.h"                 // for initCC1101once
#include <Wire.h>

/*********************************************************************
 **  Function: begin_storage
 **  Config LittleFS and SD storage
 *********************************************************************/
void begin_storage() {
    if (!LittleFS.begin(true)) { LittleFS.format(), LittleFS.begin(); }
    bool checkFS = setupSdCard();
    bruceConfig.fromFile(checkFS);
    bruceConfigPins.fromFile(checkFS);
}

/*********************************************************************
 **  Function: _setup_gpio()
 **  Sets up a weak (empty) function to be replaced by /ports/* /interface.h
 *********************************************************************/
void _setup_gpio() __attribute__((weak));
void _setup_gpio() {}

/*********************************************************************
 **  Function: _post_setup_gpio()
 **  Sets up a weak (empty) ***********************st_setup_gpio() __attribute__((weak));
void _post_setup_gpio() {}

/*********************************************************************
 **  Function: setup_gpio
 **  Setup GPIO pins
 *********************************************************************/
void setup_gpio() {

    // init setup from /ports/*/interface.h
    _setup_gpio();

    // Smoochiee v2 uses a AW9325 tro control GPS, MIC, Vibro and CC1101 RX/TX powerlines
    ioExpander.init(IO_EXPANDER_ADDRESS, &Wire);

#if TFT_MOSI > 0
    if (bruceConfigPins.CC1101_bus.mosi == (gpio_num_t)TFT_MOSI)
        initCC1101once(&tft.getSPIinstance()); // (T_EMBED), CORE2 and others
    else
#endif
        if (bruceConfigPins.CC1101_bus.mosi == bruceConfigPins.SDCARD_bus.mosi)
        initCC1101once(&sdcardSPI); // (ARDUINO_M5STACK_CARDPUTER) and (ESP32S3DEVKITC1) and devices that
                                    // share CC1101 pin with only SDCard
    else initCC1101once(NULL);
    // (ARDUINO_M5STICK_C_PLUS) || (ARDUINO_M5STICK_C_PLUS2) and others that doesn´t share SPI with
    // other devices (need to change it when Bruce board comes to shore)
}

/*********************************************************************
 **  Function: begin_tft
 **  Config tft
 *********************************************************************/
void begin_tft() {
    tft.setRotation(bruceConfigPins.rotation); // sometimes it misses the first command
    tft.invertDisplay(bruceConfig.colorInverted);
    tft.setRotation(bruceConfigPins.rotation);
    tftWidth = tft.width();
#ifdef HAS_TOUCH
    tftHeight = tft.height() - 20;
#else
    tftHeight = tft.height();
#endif
    resetTftDisplay();
    setBrightness(bruceConfig.bright, false);
}

/*********************************************************************
 **  Function: boot_screen
 **  Draw boot screen
 *********************************************************************/
void boot_screen() {
    tft.setTextColor(bruceConfig.priColor, bruceConfig.bgColor);
    tft.setTextSize(FM);
    tft.drawPixel(0, 0, bruceConfig.bgColor);
    tft.drawCentreString("Bruce", tftWidth / 2, 10, 1);
    tft.setTextSize(FP);
    tft.drawCentreString(BRUCE_VERSION, tftWidth / 2, 25, 1);
    tft.setTextSize(FM);
    tft.drawCentreString(
        "PREDATORY FIRMWARE", tftWidth / 2, tftHeight + 2, 1
    ); // will draw outside the screen on non touch devices
}

/*********************************************************************
 **  Function: boot_screen_anim
 **  Draw boot screen
 *********************************************************************/
void boot_screen_anim() {
    boot_screen();
    int i = millis();
    // checks for boot.jpg in SD and LittleFS for customization
    int boot_img = 0;
    bool drawn = false;
    if (sdcardMounted) {
        if (SD.exists("/boot.jpg")) boot_img = 1;
        else if (SD.exists("/boot.gif")) boot_img = 3;
    }
    if (boot_img == 0 && LittleFS.exists("/boot.jpg")) boot_img = 2;
    else if (boot_img == 0 && LittleFS.exists("/boot.gif")) boot_img = 4;
    if (bruceConfig.theme.boot_img) boot_img = 5; // override others

    tft.drawPixel(0, 0, 0);       // Forces back communication with TFT, to avoid ghosting
                                  // Start image loop
    while (millis() < i + 7000) { // boot image lasts for 5 secs
        if ((millis() - i > 2000) && !drawn) {
            tft.fillRect(0, 45, tftWidth, tftHeight - 45, bruceConfig.bgColor);
            if (boot_img > 0 && !drawn) {
                tft.fillScreen(bruceConfig.bgColor);
                if (boot_img == 5) {
                    drawImg(
                        *bruceConfig.themeFS(),
                        bruceConfig.getThemeItemImg(bruceConfig.theme.paths.boot_img),
                        0,
                        0,
                        true,
                        3600
                    );
                    Serial.println("Image from SD theme");
                } else if (boot_img == 1) {
                    drawImg(SD, "/boot.jpg", 0, 0, true);
                    Serial.println("Image from SD");
                } else if (boot_img == 2) {
                    drawImg(LittleFS, "/boot.jpg", 0, 0, true);
                    Serial.println("Image from LittleFS");
                } else if (boot_img == 3) {
                    drawImg(SD, "/boot.gif", 0, 0, true, 3600);
                    Serial.println("Image from SD");
                } else if (boot_img == 4) {
                    drawImg(LittleFS, "/boot.gif", 0, 0, true, 3600);
                    Serial.println("Image from LittleFS");
                }
                tft.drawPixel(0, 0, 0); // Forces back communication with TFT, to avoid ghosting
            }
            drawn = true;
        }
#if !defined(LITE_VERSION)
        if (!boot_img && (millis() - i > 2200) && (millis() - i) < 2700)
            tft.drawRect(2 * tftWidth / 3, tftHeight / 2, 2, 2, bruceConfig.priColor);
        if (!boot_img && (millis() - i > 2700) && (millis() - i) < 2900)
            tft.fillRect(0, 45, tftWidth, tftHeight - 45, bruceConfig.bgColor);
        if (!boot_img && (millis() - i > 2900) && (millis() - i) < 3400)
            tft.drawXBitmap(
                2 * tftWidth / 3 - 30,
                5 + tftHeight / 2,
                bruce_small_bits,
                bruce_small_width,
                bruce_small_height,
                bruceConfig.bgColor,
                bruceConfig.priColor
            );
        if (!boot_img && (millis() - i > 3400) && (millis() - i) < 3600) tft.fillScreen(bruceConfig.bgColor);
        if (!boot_img && (millis() - i > 3600))
            tft.drawXBitmap(
                (tftWidth - 238) / 2,
                (tftHeight - 133) / 2,
                bits,
                bits_width,
                bits_height,
                bruceConfig.bgColor,
                bruceConfig.priColor
            );
#endif
        if (check(AnyKeyPress)) // If any key or M5 key is pressed, it'll jump the boot screen
        {
            tft.fillScreen(bruceConfig.bgColor);
            delay(10);
            return;
        }
    }

    // Clear splashscreen
    tft.fillScreen(bruceConfig.bgColor);
}

/*********************************************************************
 **  Function: init_clock
 **  Clock initialisation for propper display in menu
 *********************************************************************/
void init_clock() {
#if defined(HAS_RTC)
    _rtc.begin();
#if defined(HAS_RTC_BM8563)
    _rtc.GetBm8563Time();
#endif
#if defined(HAS_RTC_PCF85063A)
    _rtc.GetPcf85063Time();
#endif
    _rtc.GetTime(&_time);
    _rtc.GetDate(&_date);

    struct tm timeinfo = {};
    timeinfo.tm_sec = _time.Seconds;
    timeinfo.tm_min = _time.Minutes;
    timeinfo.tm_hour = _time.Hours;
    timeinfo.tm_mday = _date.Date;
    timeinfo.tm_mon = _date.Month > 0 ? _date.Month - 1 : 0;
    timeinfo.tm_year = _date.Year >= 1900 ? _date.Year - 1900 : 0;
    time_t epoch = mktime(&timeinfo);
    struct timeval tv = {.tv_sec = epoch};
    settimeofday(&tv, nullptr);
#else
    struct tm timeinfo = {};
    timeinfo.tm_year = CURRENT_YEAR - 1900;
    timeinfo.tm_mon = 0x05;
    timeinfo.tm_mday = 0x14;
    time_t epoch = mktime(&timeinfo);
    rtc.setTime(epoch);
    clock_set = true;
    struct timeval tv = {.tv_sec = epoch};
    settimeofday(&tv, nullptr);
#endif
}

/*********************************************************************
 **  Function: init_led
 **  Led initialisation
 *********************************************************************/
void init_led() {
#ifdef HAS_RGB_LED
    beginLed();
#endif
}

/*********************************************************************
 **  Function: startup_sound
 **  Play sound or tone depending on device hardware
 *********************************************************************/
void startup_sound() {
    if (bruceConfig.soundEnabled == 0) return; // if sound is disabled, do not play sound
#if !defined(LITE_VERSION)
#if defined(BUZZ_PIN)
    // Bip M5 just because it can. Does not bip if splashscreen is bypassed
    _tone(5000, 50);
    delay(200);
    _tone(5000, 50);
    /*  2fix: menu infinite loop */
#elif defined(HAS_NS4168_SPKR)
    // play a boot sound
    if (bruceConfig.theme.boot_sound) {
        playAudioFile(bruceConfig.themeFS(), bruceConfig.getThemeItemImg(bruceConfig.theme.paths.boot_sound));
    } else if (SD.exists("/boot.wav")) {
        playAudioFile(&SD, "/boot.wav");
    } else if (LittleFS.exists("/boot.wav")) {
        playAudioFile(&LittleFS, "/boot.wav");
    }
#endif
#endif
}

/*********************************************************************
 **  Function: setup
 **  Where the devices are started and variables set
 *********************************************************************/
void setup() {
    Serial.setRxBufferSize(
        SAFE_STACK_BUFFER_SIZE / 4
    ); // Must be invoked before Serial.begin(). Default is 256 chars
    Serial.begin(115200);

    log_d("Total heap: %d", ESP.getHeapSize());
    log_d("Free heap: %d", ESP.getFreeHeap());
    if (psramInit()) log_d("PSRAM Started");
    if (psramFound()) log_d("PSRAM Found");
    else log_d("PSRAM Not Found");
    log_d("Total PSRAM: %d", ESP.getPsramSize());
    log_d("Free PSRAM: %d", ESP.getFreePsram());

    // declare variables
    prog_handler = 0;
    sdcardMounted = false;
    wifiConnected = false;
    BLEConnected = false;
    bruceConfig.bright = 100; // theres is no value yet
    bruceConfigPins.rotation = ROTATION;
    setup_gpio();
#if defined(HAS_SCREEN)
    tft.init();
    tft.setRotation(bruceConfigPins.rotation);
    tft.fillScreen(TFT_BLACK);
    // bruceConfig is not read yet.. just to show something on screen due to long boot time
    tft.setTextColor(TFT_PURPLE, TFT_BLACK);
    tft.drawCentreString("Booting", tft.width() / 2, tft.height() / 2, 1);
#else
    tft.begin();
#endif
    begin_storage();
    begin_tft();
    init_clock();
    init_led();

    options.reserve(20); // preallocate some options space to avoid fragmentation

    // Set WiFi country to avoid warnings and ensure max power
    const wifi_country_t country = {
        .cc = "US",
        .schan = 1,
        .nchan = 14,
#ifdef CONFIG_ESP_PHY_MAX_TX_POWER
        .max_tx_power = CONFIG_ESP_PHY_MAX_TX_POWER, // 20
#endif
        .policy = WIFI_COUNTRY_POLICY_MANUAL
    };

    esp_wifi_set_max_tx_power(80); // 80 translates to 20dBm
    esp_wifi_set_country(&country);

    // Some GPIO Settings (such as CYD's brightness control must be set after tft and sdcard)
    _post_setup_gpio();
    // end of post gpio begin

    // #ifndef USE_TFT_eSPI_TOUCH
    // This task keeps running all the time, will never stop
    xTaskCreate(
        taskInputHandler,              // Task function
        "InputHandler",                // Task Name
        INPUT_HANDLER_TASK_STACK_SIZE, // Stack size
        NULL,                          // Task parameters
        2,                             // Task priority (0 to 3), loopTask has priority 2.
        &xHandle                       // Task handle (not used)
    );
    // #endif
#if defined(HAS_SCREEN)
    bruceConfig.openThemeFile(bruceConfig.themeFS(), bruceConfig.themePath, false);
    if (!bruceConfig.instantBoot) {
        boot_screen_anim();
        startup_sound();
    }
    if (bruceConfig.wifiAtStartup) {
        log_i("Loading Wifi at Startup");
        xTaskCreate(
            wifiConnectTask,   // Task function
            "wifiConnectTask", // Task Name
            4096,              // Stack size
            NULL,              // Task parameters
            2,                 // Task priority (0 to 3), loopTask has priority 2.
            NULL               // Task handle (not used)
        );
    }
#endif
    //  start a task to handle serial commands while the webui is running
    startSerialCommandsHandlerTask(true);

    wakeUpScreen();
    if (bruceConfig.startupApp != "" && !startupApp.startApp(bruceConfig.startupApp)) {
        bruceConfig.setStartupApp("");
    }
}

/**********************************************************************
 **  Function: loop
 **  Main loop
 **********************************************************************/
#if defined(HAS_SCREEN)
void loop() {
#if !defined(LITE_VERSION) && !defined(DISABLE_INTERPRETER)
    if (interpreter_state > 0) {
        vTaskDelay(pdMS_TO_TICKS(10));
        interpreter_state = 2;
        Serial.println("Entering interpreter...");
        while (interpreter_state > 0) { vTaskDelay(pdMS_TO_TICKS(500)); }
        if (interpreter_state == 0) {
            Serial.println("Interpreter put to background.");
        } else {
            Serial.println("Exiting interpreter...");
        }
        if (interpreter_state == -1) { interpreterTaskHandler = NULL; }
        previousMillis = millis(); // ensure that will not dim screen when get back to menu
    }
#endif
    tft.fillScreen(bruceConfig.bgColor);

    mainMenu.begin();
    delay(1);
}
#else

void loop() {
    tft.setLogging();
    Serial.println(
        "\n"
        "██████  ██████  ██    ██  ██████ ███████ \n"
        "██   ██ ██   ██ ██    ██ ██      ██      \n"
        "██████  ██████  ██    ██ ██      █████   \n"
        "██   ██ ██   ██ ██    ██ ██      ██      \n"
        "██████  ██   ██  ██████   ██████ ███████ \n"
        "                                         \n"
        "         PREDATORY FIRMWARE\n\n"
        "Tips: Connect to the WebUI for better experience\n"
        "      Add your network by sending: wifi add ssid password\n\n"
        "At your command:"
    );

    // Enable navigation through webUI
    tft.fillScreen(bruceConfig.bgColor);
    mainMenu.begin();
    vTaskDelay(10 / portTICK_PERIOD_MS);
}
#endif

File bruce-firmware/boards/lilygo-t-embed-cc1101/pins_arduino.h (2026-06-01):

#ifdef T_EMBED_1101
#ifndef __T_EMBED_H__
#define __T_EMBED_H__
#define T_EMBED

#include "soc/soc_caps.h"
#include <stdint.h>

// Main I2C Bus
#define SPI_SS_PIN 8
#define SPI_MOSI_PIN 9
#define SPI_MISO_PIN 10
#define SPI_SCK_PIN 11
static const uint8_t SS = SPI_SS_PIN;
static const uint8_t MOSI = SPI_MOSI_PIN;
static const uint8_t SCK = SPI_MISO_PIN;
static const uint8_t MISO = SPI_SCK_PIN;

// Set Main I2C Bus
#define GROVE_SDA 8
#define GROVE_SCL 18
static const uint8_t SDA = GROVE_SDA;
static const uint8_t SCL = GROVE_SCL;

// TFT_eSPI display
#define ST7789_DRIVER 1
#define USER_SETUP_LOADED
#define USE_HSPI_PORT
#define SMOOTH_FONT 1
#define TFT_INVERSION_ON
#define TFT_WIDTH 170
#define TFT_HEIGHT 320
#define TFT_BL 21
#define TFT_MISO SPI_MISO_PIN
#define TFT_MOSI SPI_MOSI_PIN
#define TFT_SCLK SPI_SCK_PIN
#define TFT_CS 41
#define TFT_DC 16
#define TFT_RST 40
#define SPI_FREQUENCY 80000000
#define SPI_READ_FREQUENCY 20000000

// Display Setup
#define HAS_SCREEN
#define ROTATION 3
#define MINBRIGHT (uint8_t)1
#define PIN_POWER_ON 15

// Font Sizes
#define FP 1
#define FM 2
#define FG 3

// SD Card
#define SDCARD_CS 13
#define SDCARD_MISO SPI_MISO_PIN
#define SDCARD_MOSI SPI_MOSI_PIN
#define SDCARD_SCK SPI_SCK_PIN

// NRF24 - Over QWIIC Port #2
#define USE_NRF24_VIA_SPI
#define NRF24_CE_PIN 43
#define NRF24_SS_PIN 44
#define NRF24_MOSI_PIN SDCARD_MOSI
#define NRF24_SCK_PIN SDCARD_SCK
#define NRF24_MISO_PIN SDCARD_MISO

// CC1101
#define USE_CC1101_VIA_SPI
#define CC1101_GDO0_PIN 3
#define CC1101_GDO2_PIN 38
#define CC1101_SW1_PIN 47
#define CC1101_SW0_PIN 48
#define CC1101_SS_PIN 12
#define CC1101_MISO_PIN SPI_MISO_PIN
#define CC1101_MOSI_PIN SPI_MOSI_PIN
#define CC1101_SCK_PIN SPI_SCK_PIN

// W5500 over QWIIC port
#define USE_W5500_VIA_SPI
#define W5500_SS_PIN 44
#define W5500_MOSI_PIN SPI_MOSI_PIN
#define W5500_SCK_PIN SPI_SCK_PIN
#define W5500_MISO_PIN SPI_MISO_PIN
#define W5500_INT_PIN 43
// PN532
#define PN532_RF_REST 45
#define PN532_IRQ 17

// Mic
#define PIN_CLK 39
#define PIN_DATA 42

// Speaker
#define HAS_NS4168_SPKR
#define BCLK 46
#define WCLK 40
#define DOUT 7
#define MCLK PIN_CLK

// Serial
#define SERIAL_TX 43
#define SERIAL_RX 44
static const uint8_t TX = SERIAL_TX;
static const uint8_t RX = SERIAL_RX;
#define GPS_SERIAL_TX SERIAL_TX
#define GPS_SERIAL_RX SERIAL_RX
#define TX1 TX
#define RX1 RX

// Fuel Gauge
#define USE_BQ27220_VIA_I2C
#define BQ27220_I2C_ADDRESS 0x55
#ifdef BQ27220_I2C_SDA
#undef BQ27220_I2C_SDA
#endif
#ifdef BQ27220_I2C_SCL
#undef BQ27220_I2C_SCL
#endif
#define BQ27220_I2C_SDA GROVE_SDA
#define BQ27220_I2C_SCL GROVE_SCL

// Encoder
#define HAS_ENCODER
#define ENCODER_INA 4
#define ENCODER_INB 5
#define ENCODER_KEY 0
#define HAS_BTN 1
#define BTN_ALIAS "\"Mid\""
#define SEL_BTN ENCODER_KEY
#define UP_BTN -1
#define DW_BTN -1
#define BK_BTN 6
#define BTN_ACT LOW

// IR
#define TXLED 2
#define RXLED 1
#define LED_ON HIGH
#define LED_OFF LOW

// FM Radio
#define FM_SI4713
// RFID

#define RFID125_RX_PIN SERIAL_RX
#define RFID125_TX_PIN SERIAL_TX

// RGB LED
#define HAS_RGB_LED 1
#define RGB_LED 14
#define LED_TYPE WS2812B
#define LED_ORDER GRB
#define LED_TYPE_IS_RGBW 0
#define LED_COUNT 8
#define LED_COLOR_STEP 5
#define HAS_ENCODER_LED 1

// BadUSB
#define USB_as_HID 1

// Deepsleep
#define DEEPSLEEP_WAKEUP_PIN 6
#define DEEPSLEEP_PIN_ACT LOW
#endif /* Pins_Arduino_h */

#else // pins_arduino.h for T-Embed NON CC1101
// ********************************************************************
// ********************************************************************
// ********************************************************************
// ********************************************************************
#ifndef Pins_Arduino_h
#define Pins_Arduino_h

#include "soc/soc_caps.h"
#include <stdint.h>

// Lite Version
// #define LITE_VERSION 1

// Main I2C Bus
#define SPI_SS_PIN 16 // NFC_CS
#define SPI_MOSI_PIN 41
#define SPI_MISO_PIN 38 // https://github.com/pr3y/Bruce/issues/1130
#define SPI_SCK_PIN 40
static const uint8_t SS = SPI_SS_PIN;
static const uint8_t MOSI = SPI_MOSI_PIN;
static const uint8_t SCK = SPI_MISO_PIN;
static const uint8_t MISO = SPI_SCK_PIN;

// Set Main I2C Bus
#define GROVE_SDA 44
#define GROVE_SCL 43
static const uint8_t SDA = GROVE_SDA;
static const uint8_t SCL = GROVE_SCL;

// TFT_eSPI display
#define ST7789_DRIVER 1
#define USER_SETUP_LOADED
#define TFT_BACKLIGHT_ON 1
#define USE_HSPI_PORT
#define SMOOTH_FONT 1
#define TFT_WIDTH 170
#define TFT_HEIGHT 320
#define TFT_BL 15
#define TFT_MISO -1
#define TFT_MOSI 11
#define TFT_SCLK 12
#define TFT_CS 10
#define TFT_DC 13
#define TFT_RST 9
#define TOUCH_CS -1
#define SPI_FREQUENCY 40000000
#define SPI_READ_FREQUENCY 20000000
#define SPI_TOUCH_FREQUENCY 2500000

// Display Setup#
#define HAS_SCREEN
#define ROTATION 3
#define MINBRIGHT (uint8_t)1
#define PIN_POWER_ON 46

// Font Sizes#
#define FP 1
#define FM 2
#define FG 3
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

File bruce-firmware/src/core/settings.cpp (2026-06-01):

#include "settings.h"
#include "core/led_control.h"
#include "core/wifi/wifi_common.h"
#include "current_year.h"
#include "display.h"
#if !defined(LITE_VERSION) && !defined(DISABLE_INTERPRETER)
#include "modules/bjs_interpreter/interpreter.h"
#endif
#include "modules/ble_api/ble_api.hpp"
#include "modules/others/qrcode_menu.h"
#include "modules/rf/rf_utils.h" // for initRfModule
#include "mykeyboard.h"
#include "powerSave.h"
#include "sd_functions.h"
#include "settingsColor.h"
#include "utils.h"
#include <ELECHOUSE_CC1101_SRC_DRV.h>
#include <globals.h>

int currentScreenBrightness = -1;

// This function comes from interface.h
void _setBrightness(uint8_t brightval) {}

/*********************************************************************
**  Function: setBrightness
**  set brightness value
**********************************************************************/
void setBrightness(uint8_t brightval, bool save) {
    if (bruceConfig.bright > 100) bruceConfig.setBright(100);
    _setBrightness(brightval);
    delay(10);

    currentScreenBrightness = brightval;
    if (save) { bruceConfig.setBright(brightval); }
}

/*********************************************************************
**  Function: getBrightness
**  get brightness value
**********************************************************************/
void getBrightness() {
    if (bruceConfig.bright > 100) {
        bruceConfig.setBright(100);
        _setBrightness(bruceConfig.bright);
        delay(10);
        setBrightness(100);
    }

    _setBrightness(bruceConfig.bright);
    delay(10);

    currentScreenBrightness = bruceConfig.bright;
}

/*********************************************************************
**  Function: gsetRotation
**  get/set rotation value
**********************************************************************/
int gsetRotation(bool set) {
    int getRot = bruceConfigPins.rotation;
    int result = ROTATION;
    int mask = ROTATION > 1 ? -2 : 2;

    options = {
        {"Default",         [&]() { result = ROTATION; }                        },
        {"Landscape (180)", [&]() { result = ROTATION + mask; }                 },
#if TFT_WIDTH >= 170 && TFT_HEIGHT >= 240
        {"Portrait (+90)",  [&]() { result = ROTATION > 0 ? ROTATION - 1 : 3; } },
        {"Portrait (-90)",  [&]() { result = ROTATION == 3 ? 0 : ROTATION + 1; }},

#endif
    };
    addOptionToMainMenu();
    if (set) loopOptions(options);
    else result = getRot;

    if (result > 3 || result < 0) {
        result = ROTATION;
        set = true;
    }
    if (set) {
        bruceConfigPins.setRotation(result);
        tft.setRotation(result);
        tft.setRotation(result); // must repeat, sometimes ESP32S3 miss one SPI command and it just
                                 // jumps this step and don't rotate
    }
    returnToMenu = true;

    if (result & 0b01) { // if 1 or 3
        tftWidth = TFT_HEIGHT;
#if defined(HAS_TOUCH)
        tftHeight = TFT_WIDTH - 20;
#else
        tftHeight = TFT_WIDTH;
#endif
    } else { // if 2 or 0
        tftWidth = TFT_WIDTH;
#if defined(HAS_TOUCH)
        tftHeight = TFT_HEIGHT - 20;
#else
        tftHeight = TFT_HEIGHT;
#endif
    }
    return result;
}

/*********************************************************************
**  Function: setBrightnessMenu
**  Handles Menu to set brightness
**********************************************************************/
void setBrightnessMenu() {
    int idx = 0;
    if (bruceConfig.bright == 100) idx = 0;
    else if (bruceConfig.bright == 75) idx = 1;
    else if (bruceConfig.bright == 50) idx = 2;
    else if (bruceConfig.bright == 25) idx = 3;
    else if (bruceConfig.bright == 1) idx = 4;
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

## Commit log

2026-06-01 Add ESP32-S3 Bruce Firmware project
    [custom_16Mb.csv, custom_4Mb.csv, custom_4Mb_full.csv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]
2026-06-01 Improvements to the wiring diagram
    [wiring-diagram.fzz]
2026-06-01 Wiring diagram for individual modules
2026-06-01 New photos of the PCB assembly.
2026-06-02 More information added to "DEVICE INFO"
